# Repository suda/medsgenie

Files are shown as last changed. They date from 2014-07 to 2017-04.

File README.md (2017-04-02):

# Internet connected pill dispenser

## Revisions

### Mark I

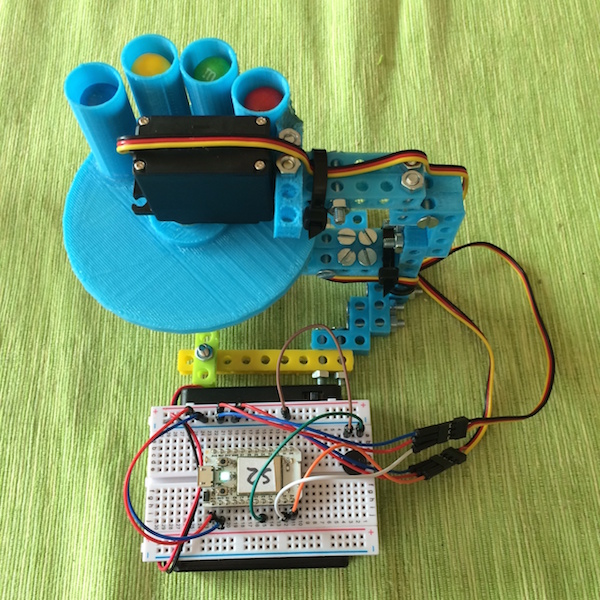
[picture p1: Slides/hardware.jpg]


Done during [BattleHack Warsaw](https://2014.battlehack.org/warsaw/) hackathon (got 2nd place).

TODO: Mention bitbeam

### Mark II

![]()

Revised version made for CNBC Cloud Challenge show. Improvements include less parts requiring glue and built in studs for servos. Device also contains a screen and a button.

### Mark III aka "Gato"

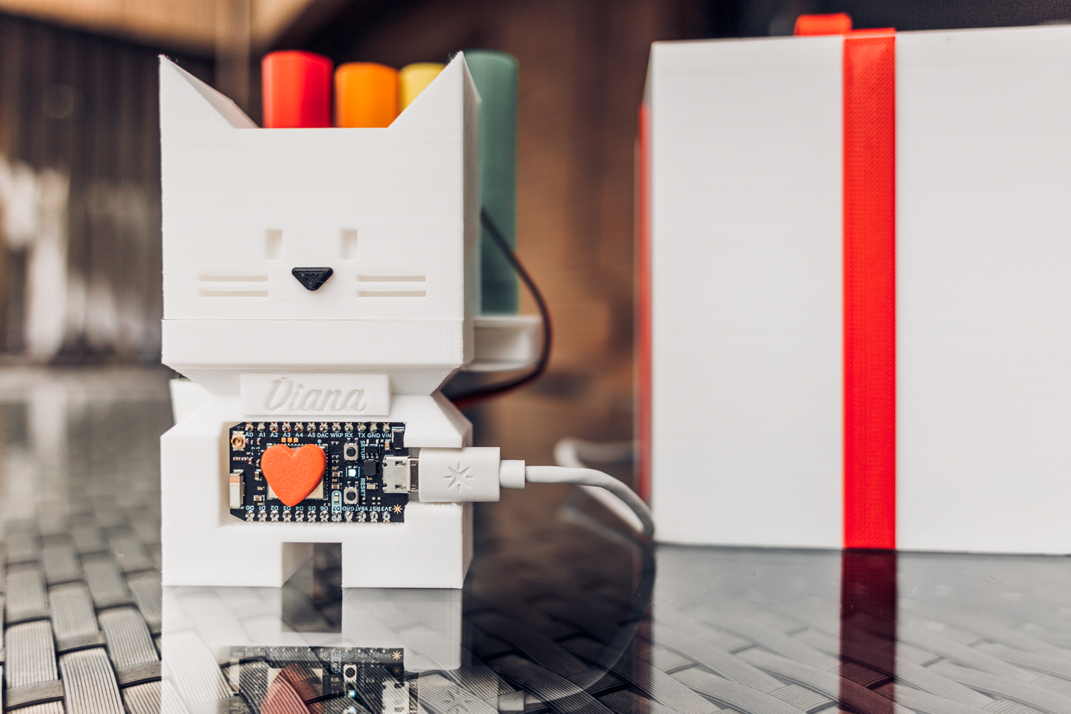
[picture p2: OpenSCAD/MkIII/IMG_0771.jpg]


Custom build as a gift. Stylized to look as a cat and comes with [it's own webapp](Gato).

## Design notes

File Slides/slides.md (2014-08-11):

# 💊 Meds Genie

---

# Grandma
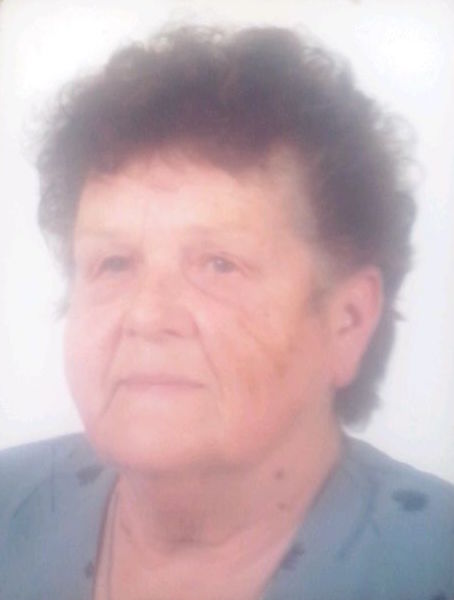
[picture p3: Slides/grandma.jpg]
Halina Szymczak


---

# Automatic Pill Dispenser
Hardware

---

# Spark Core
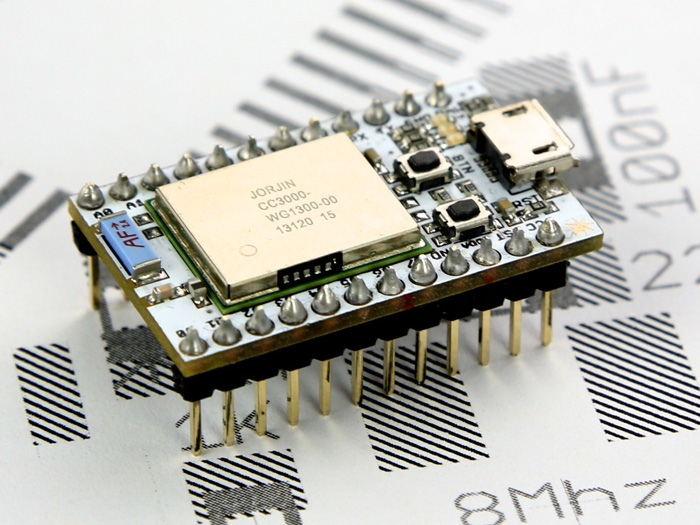
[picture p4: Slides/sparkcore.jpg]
Spark Core


---

# All 3D Printed during BattleHack
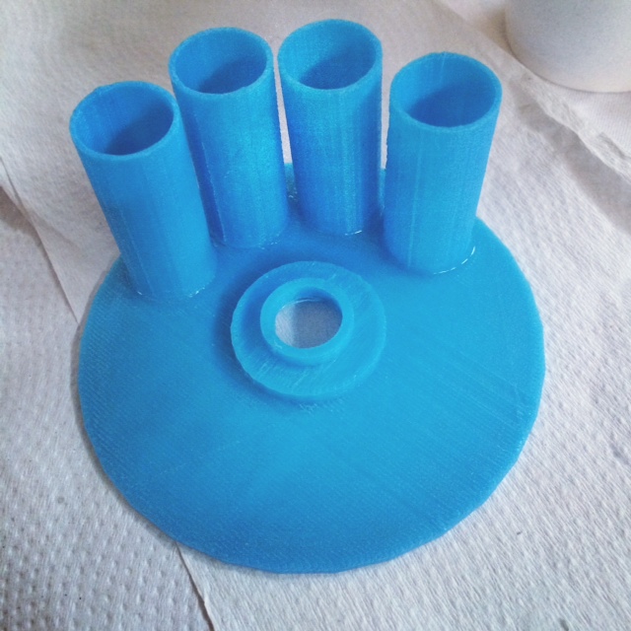
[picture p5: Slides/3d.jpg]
3D Printed Parts


---

# App for grandkids
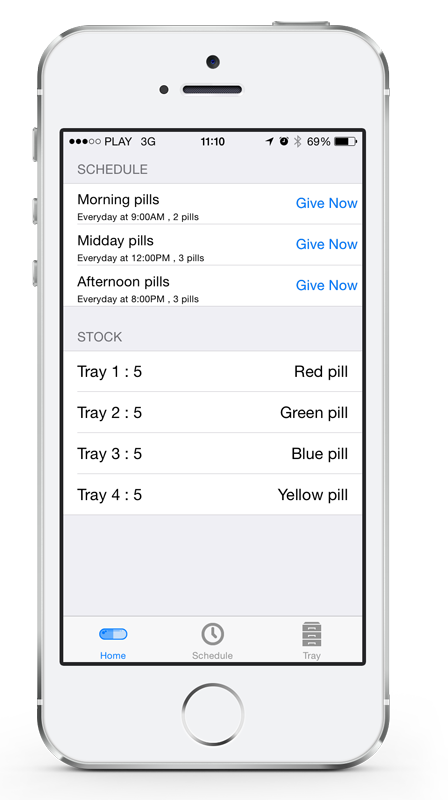
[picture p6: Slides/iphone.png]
iPhone Companion App


---

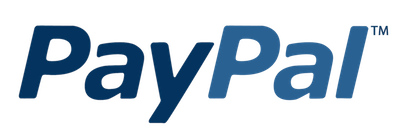
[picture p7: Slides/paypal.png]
PayPal

# Future Payments

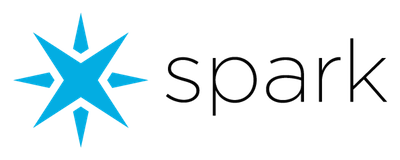
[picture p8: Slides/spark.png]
Spark Cloud

# Spark Cloud

---

# Demo Time

---

# https://github.com/suda/medsgenie

---

# Wojtek Chojnacki @chojnac
# Wojtek Siudzinski @suda

---

# 💊 Meds Genie

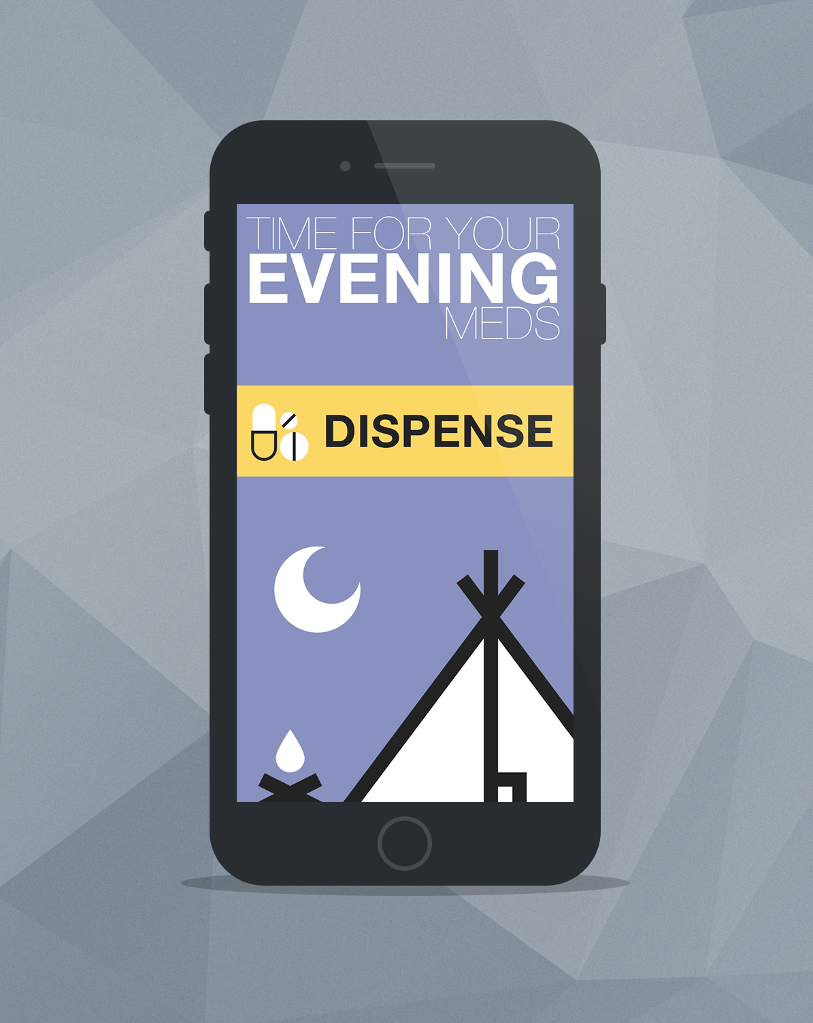
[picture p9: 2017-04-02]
mockup.png

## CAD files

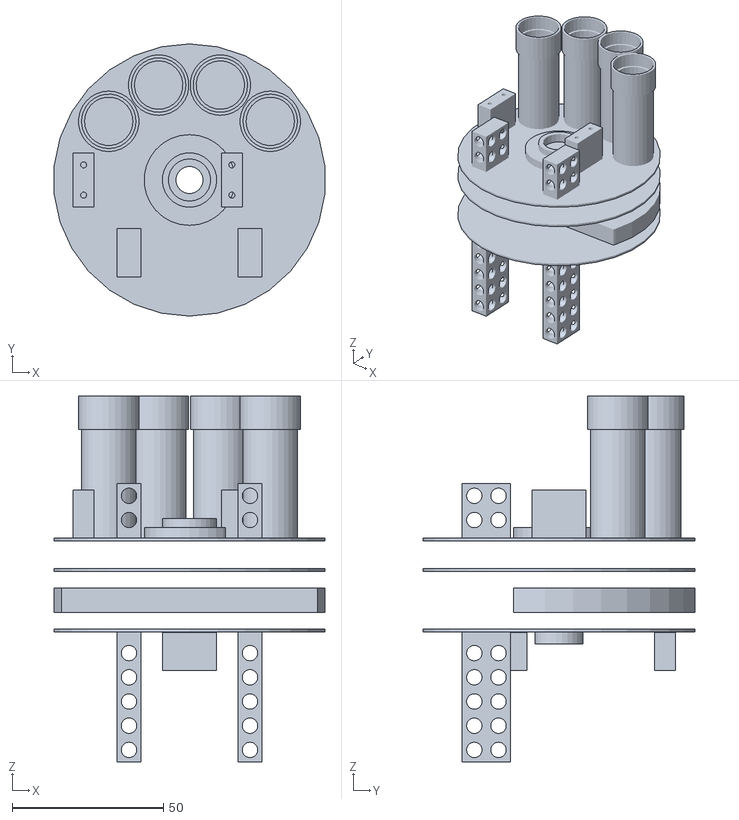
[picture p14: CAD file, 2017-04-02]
OpenSCAD/MkII/complete.stl
89.5 x 90.0 x 121.0

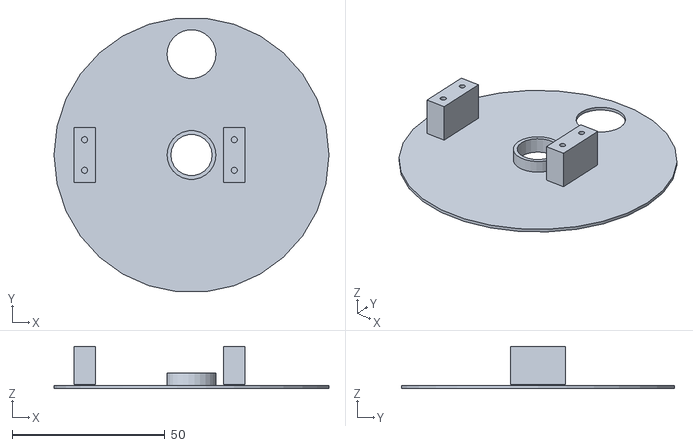
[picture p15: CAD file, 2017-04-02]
OpenSCAD/MkII/wheel4_simple.stl
90.0 x 89.5 x 13.8

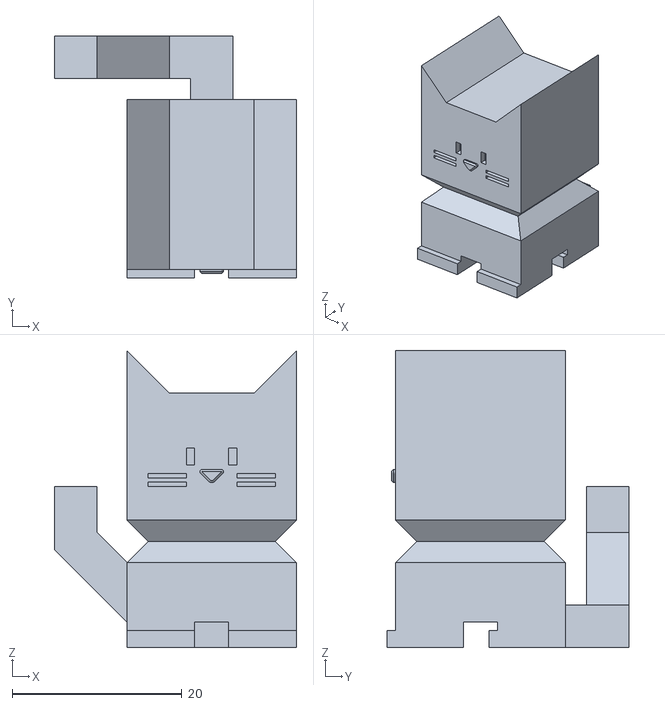
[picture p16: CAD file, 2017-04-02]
OpenSCAD/MkIII/calicat.stl
28.5 x 28.5 x 35.0

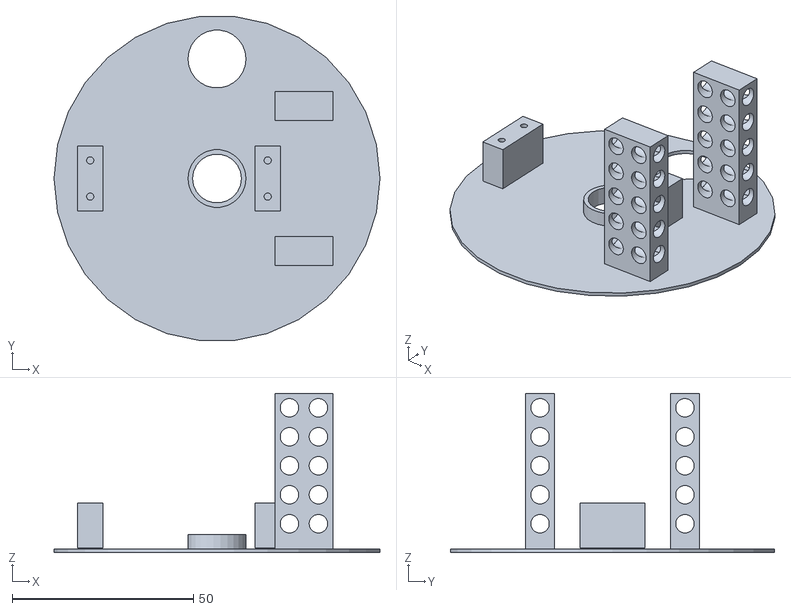
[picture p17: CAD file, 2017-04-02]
OpenSCAD/MkII/wheel4.stl
90.0 x 89.5 x 44.0

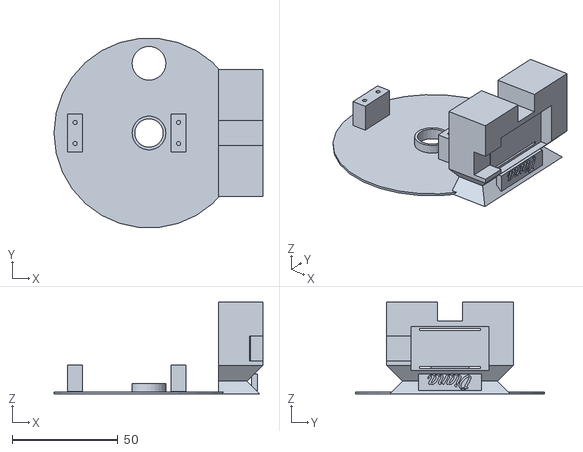
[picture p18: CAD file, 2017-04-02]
OpenSCAD/MkIII/wheel4_gato.stl
99.0 x 89.5 x 43.5

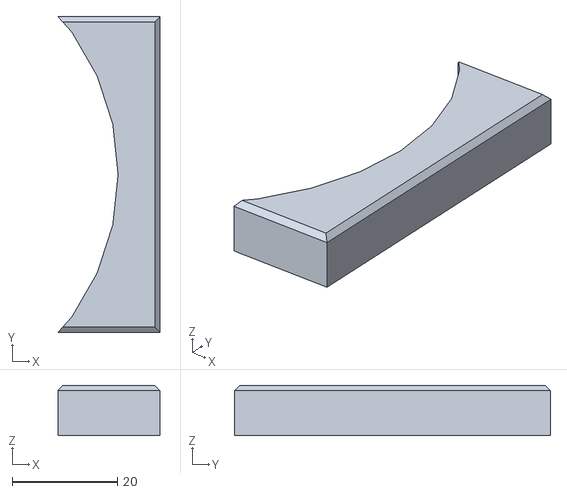
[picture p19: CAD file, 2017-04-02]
OpenSCAD/MkIII/middle_gato.stl
19.5 x 60.0 x 9.50

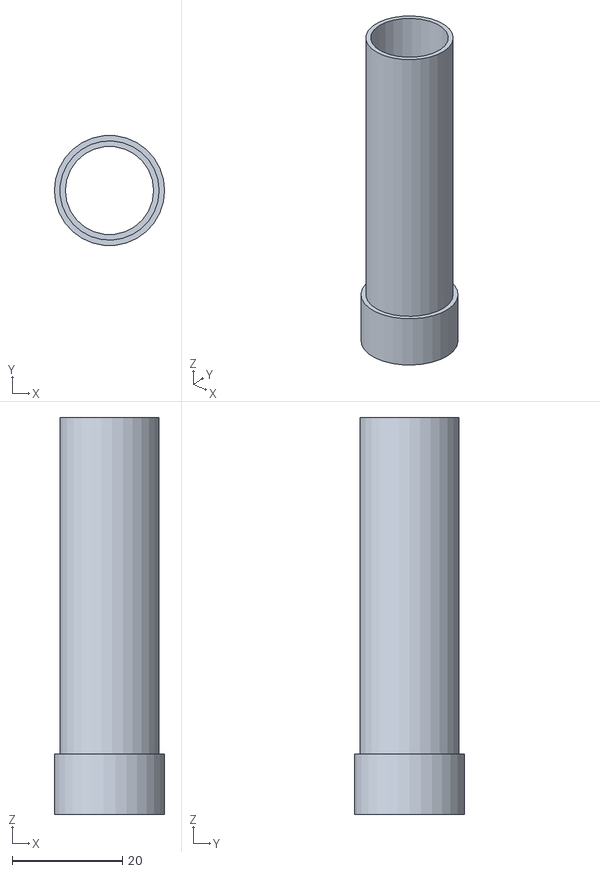
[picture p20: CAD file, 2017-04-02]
OpenSCAD/MkII/tube.stl
20.0 x 19.9 x 72.0

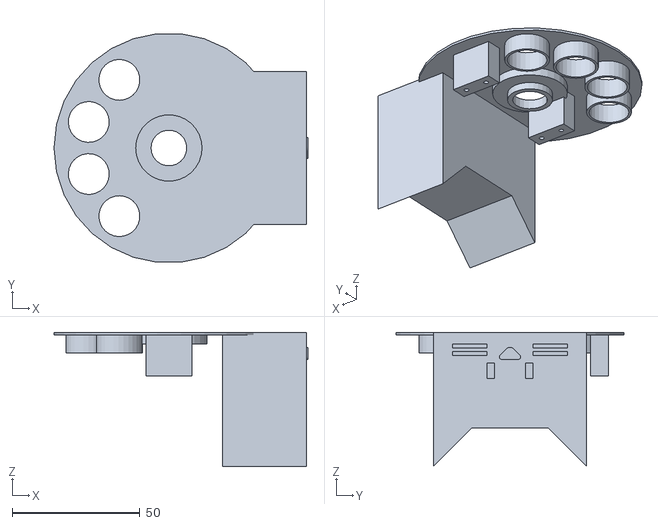
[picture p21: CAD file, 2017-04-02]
OpenSCAD/MkIII/wheel1_gato.stl
99.5 x 89.5 x 52.5

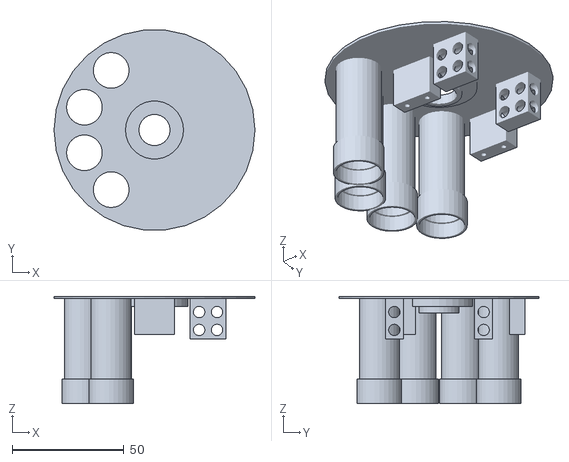
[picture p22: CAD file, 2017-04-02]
OpenSCAD/MkII/wheel1.stl
90.0 x 89.5 x 48.0

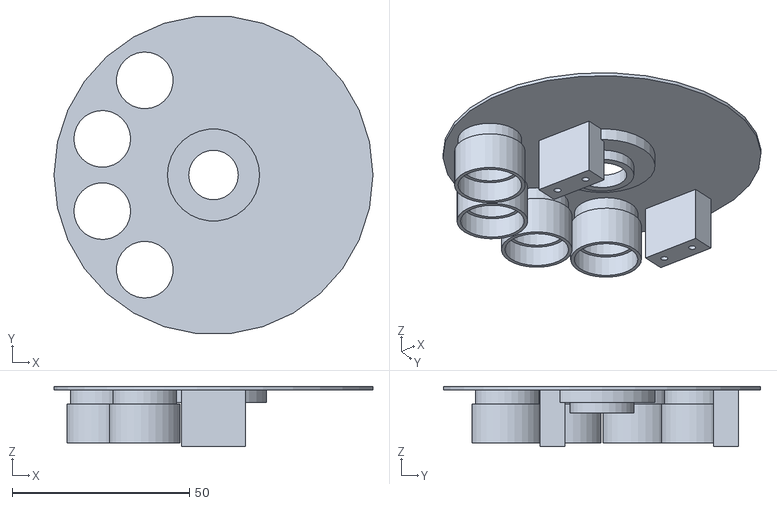
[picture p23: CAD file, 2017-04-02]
OpenSCAD/MkII/wheel1_simple.stl
90.0 x 89.5 x 17.0

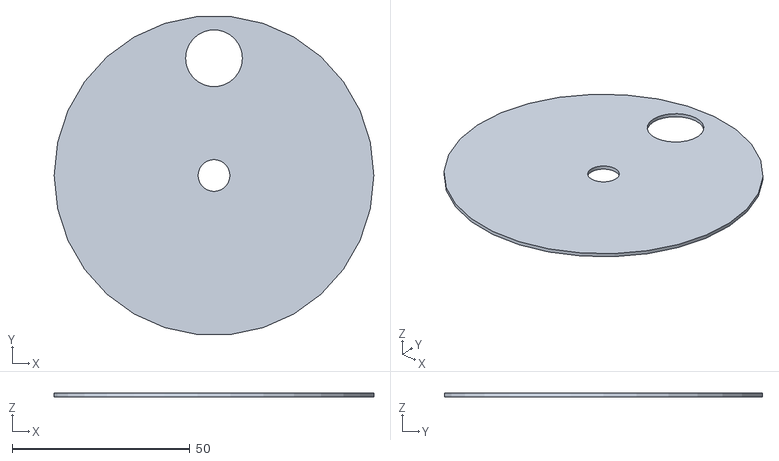
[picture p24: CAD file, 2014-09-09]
OpenSCAD/MkII/wheel2.stl
90.0 x 89.5 x 1.00

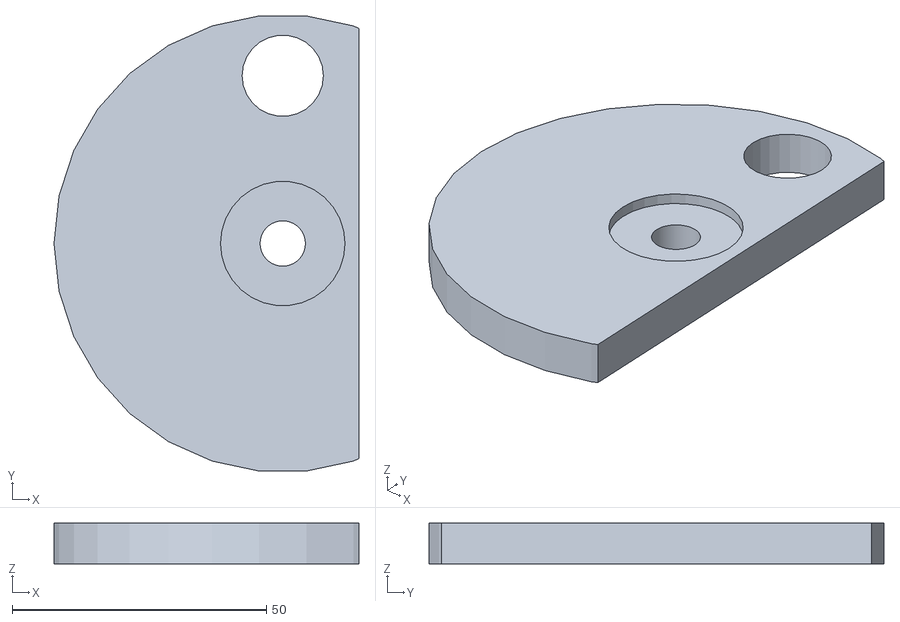
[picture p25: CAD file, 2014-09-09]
OpenSCAD/MkII/wheel3.stl
60.0 x 89.5 x 8.00

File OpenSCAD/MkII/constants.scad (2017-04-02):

//-------------------------------------------------------------
//-- Futaba Horn from Servo wheel by Juan Gonzalez (obijuan) juan@iearobotics.com
//-------------------------------------------------------------

//-- Wheel parameters
wheel_or_idiam = 50;                   //-- O-ring inner diameter
wheel_or_diam = 1;                     //-- O-ring section diameter
wheel_height = 2*wheel_or_diam+0;     //-- Wheel height: change the 0 for 
                                      //-- other value (0 equals minimun height)
//-- Parameters common to all horns
horn_drill_diam = 2;
horn_height = 8;        //-- Total height: shaft + plate
horn_plate_height = 2;  //-- plate height

//-- Futaba 3003 servo rounded horn parameters
rh_diam1 = 8.5;  //-- Rounded horn small diameter
rh_diam2 = 24; //-- Rounded horn big diameter
rounded_horn_drill_distance = 7.3;

//-- Futaba 3003 4-arm horn parameters
a4h_end_diam = 5;
a4h_center_diam = 10;
a4h_arm_length = 15;
a4h_drill_distance = 13.3;

//-- Pill parameters
pill_diam = 16;
pill_height = 8;
pill_holder = pill_diam * 1.5;

length = 70;


module motorPeg(height=12.5) {
    difference() {
        cube([7, 18, height], center=true);
        translate([0, -5, 0])
            cylinder(r=1, h=20, center=true, $fn=100);
        translate([0, 5, 0])
            cylinder(r=1, h=20, center=true, $fn=100);
    }
}

module gato() {
    scale(3)
        rotate([180, 0, -90])
            difference() {
                import("calicat.stl", convexity=3);
                translate([0, 8, 0])
                    cube([50, 50, 50]);
            }
}

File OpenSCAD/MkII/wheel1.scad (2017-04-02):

include <constants.scad>;
include <bitbeam-beam.scad>;
include <tube.scad>;

module handle() {
    union() {
        cube([2.5, 8*2, 8]);
        translate([2.5, 0, 0])
            beam(2);            
        translate([2.5, 8, 0])
            beam(2);
    }
}

module wheel1() {
	difference() {
		cylinder(r=45, h=1, center=true);
		for (i = [1 : 4]) {
			translate([0, 0, 0])
			rotate([0,0,i*36])
				translate([0, 33, -1])
					cylinder(h=3, r=(pill_diam + 1.5) / 2);
		}

		translate([0, 0, -1])
			cylinder(r=13, h=2);
	}

	difference() {
		union() {
			translate([0, 0, -4])
				cylinder(r=15, h=4);

			translate([0, 0, -7])
				cylinder(r=9, h=3);
            
            rotate([0, 0, 270])
                translate([-35, 0, -8.5])
                    motorPeg(12+4);
            
            rotate([0, 0, 270])
                translate([14, 0, -8.5])
                    motorPeg(12+4);
		}

		translate([0, 0, -3])
			cylinder(r=13.5, h=4);

		translate([0, 0, -8])
				cylinder(r=7, h=6);
	}
    
    
	pills = 1;
	for (i = [1 : 4]) {
		translate([0, 0, -(pill_height * pills) + 1.5])
			rotate([0,0,i*36])
				translate([0, 33, -1])
					tube(pills);
	}
    
//    translate([8*2, -8*2, 0])
//        rotate([90, 90, 0])
//            handle();
//    
//    translate([8*2, 8*3, 0])
//        rotate([90, 90, 0])
//            handle();
}

//wheel1();

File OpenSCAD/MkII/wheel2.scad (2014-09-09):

include <constants.scad>;

module wheel2() {
	difference() {
		cylinder(r=45, h=1, center=true);
		for (i = [0 : 0]) {
			translate([0, 0, 0])
			rotate([0,0,i*36])
				translate([0, 33, -1])
					cylinder(h=3, r=pill_diam / 2);
		}

		//-- Inner drill
		translate([0, 0, -pill_height / 2])
			cylinder(h=pill_height, r=rh_diam1/2+0.2,$fn=100);

		//-- Carved circle for the Futaba rounded horn
		translate([0, 0, pill_height / 2 - 2])
			cylinder(r=rh_diam2/2+0.25, h=2.1, $fn=30);
	}
}

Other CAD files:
OpenSCAD/MkII/bitbeam-beam.scad
OpenSCAD/MkII/complete.scad
OpenSCAD/MkII/tube.scad
OpenSCAD/MkII/wheel3.scad
OpenSCAD/MkII/wheel4.scad
OpenSCAD/MkIII/complete_gato.scad
OpenSCAD/MkIII/middle_gato.scad
OpenSCAD/MkIII/tube.scad
OpenSCAD/MkIII/wheel1_gato.scad
OpenSCAD/MkIII/wheel3.scad
OpenSCAD/MkIII/wheel4_gato.scad

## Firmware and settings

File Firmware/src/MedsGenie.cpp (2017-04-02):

#include <Arduino.h>
#include <Debounce.h>
#include <U8x8lib.h>
#include "application.h"

#ifdef U8X8_HAVE_HW_SPI
#include <SPI.h>
#endif
#ifdef U8X8_HAVE_HW_I2C
#include <Wire.h>
#endif

SYSTEM_THREAD(ENABLED);

#include "pitches.h"
#include "types.h"

// Pins
int lockServoPin = A4;
int transportServoPin = D0;
int buzzerPin = RX;
int CLKPin = A3;
int MOSIPin = A5;
int RESPin = A0;
int DCPin = A1;
int CSPin = A2;
int btnPin = D1;

int numberOfTrays = 4;
int servoDelay = 200;
int lastLockPosition = 0;
int lastTransportPosition = 0;
int lockAngles[] = {170, 140, 98, 56, 17};
int transportAngles[] = {16, 45, 86, 128, 168};
/*int lockAngles[] = {180, 140, 100, 63, 22};
int transportAngles[] = {11, 45, 86, 128, 168};*/
bool isSignaling;
bool switchState;
unsigned long bootTime;
bool alreadyEnteredListenMode;

int melody[] = {
  NOTE_C4, NOTE_G3,NOTE_G3, NOTE_A3, NOTE_G3, 0, NOTE_B3, NOTE_C4};
int noteDurations[] = { 4, 8, 8, 4, 4, 4, 4, 4 };
state_type state = READY;

//#define USE_SCREEN

// LED status for the test signal that can be triggered from the cloud
class LEDCloudSignalStatus: public LEDStatus {
public:
  explicit LEDCloudSignalStatus(LEDPriority priority) :
        LEDStatus(LED_PATTERN_CUSTOM, priority),
        ticks_(0),
        index_(0) {
    updateColor();
  }

protected:
  virtual void update(system_tick_t t) override {
    if (t >= ticks_) {
      // Change LED color
      if (++index_ == COLOR_COUNT) {
        index_ = 0;
      }
      updateColor();
    } else {
      ticks_ -= t; // Update timing
    }
  }

private:
  uint16_t ticks_;
  uint8_t index_;

  void updateColor() {
    setColor(COLORS[index_]);
    ticks_ = 100;
  }

  static const uint32_t COLORS[];
  static const size_t COLOR_COUNT;
};
const uint32_t LEDCloudSignalStatus::COLORS[] = { 0xEE82EE, 0x4B0082, 0x0000FF, 0x00FF00, 0xFFFF00, 0xFFA500, 0xFF0000 }; // VIBGYOR
const size_t LEDCloudSignalStatus::COLOR_COUNT = sizeof(LEDCloudSignalStatus::COLORS) / sizeof(LEDCloudSignalStatus::COLORS[0]);

U8X8_SH1106_128X64_NONAME_4W_HW_SPI u8x8(CSPin, DCPin, RESPin);
Debounce button = Debounce();
Servo lockServo;
Servo transportServo;
LEDCloudSignalStatus rainbowSignal(LED_PRIORITY_IMPORTANT);

/**
 * Private functions
 */
#pragma mark Private functions

void _attachServos() {
  SPI.end();
  lockServo.attach(lockServoPin);
  transportServo.attach(transportServoPin);
}

void _updateScreen() {
  u8x8.clear();

  switch(state) {
    case READY:
      u8x8.draw2x2String(0, 1, "PRESS TO");
      u8x8.draw2x2String(0, 5, "DISPENCE");
      break;
    case WORKING:
      u8x8.draw2x2String(1, 2, "WORKING");
      u8x8.draw2x2String(1, 4, "  ...");
      break;
    case CONFIRM:
      u8x8.draw2x2String(1, 1, "CONFIRM");
      u8x8.draw2x2String(1, 5, "   ?");
      break;
  }

  u8x8.refreshDisplay();
}

void _setNewState(state_type newState) {
  state = newState;
#ifdef USE_SCREEN
  _updateScreen();
#endif
}

void _lockTo(int pos, bool skipDelay=false) {
  _attachServos();
  lockServo.write(lockAngles[pos]);
  if (!skipDelay) delay(servoDelay * abs(lastLockPosition - pos));
  lastLockPosition = pos;
}

void _transportTo(int pos, bool skipDelay=false) {
  _attachServos();
  transportServo.write(transportAngles[pos]);
  if (!skipDelay) delay(servoDelay * abs(lastTransportPosition - pos));
  lastTransportPosition = pos;
}

int _servePill(int pos) {
  // Test for oob position
  if ((pos < 0) || (pos > numberOfTrays - 1)) return 404;

  // 0 tray is drop zone. Increase position
  pos++;

  // Lock
  _lockTo(numberOfTrays);

  // Move transport under tray
  _transportTo(pos);

  // Unlock...
  _lockTo(pos, pos == numberOfTrays);

  // Let it drop
  delay(200);

  // Lock again
  _lockTo(4, pos == numberOfTrays);

  // Move transport to drop zone
  _transportTo(0);

  return 200;
}

/**
 * Particle functions
 */
#pragma mark Particle functions

int beepCommand(String command="") {
  for (int i=0; i<8; i++) {
    int noteDuration = 500/noteDurations[i];

    if (melody[i] == 0) {
      noTone(buzzerPin);
    } else {
      tone(buzzerPin, melody[i]);
    }

    delay(noteDuration);

    noTone(buzzerPin);
    int pauseBetweenNotes = noteDuration * 1.30;
    delay(pauseBetweenNotes);
  }

  return 200;
}

int servePillCommand(String command) {
  int returnCode;

  _setNewState(WORKING);
  SPI.end();
  lockServo.attach(lockServoPin);
  transportServo.attach(transportServoPin);
  rainbowSignal.setActive(true);

  String currentCommand = command;
  while (currentCommand.indexOf(",") > -1) {
      int pos = currentCommand.substring(0, currentCommand.indexOf(",")).toInt();
      String newCommand = currentCommand.substring(currentCommand.indexOf(",") + 1);
      currentCommand = newCommand;
      Serial.println(currentCommand);
      returnCode = _servePill(pos);
  }

  int pos = currentCommand.toInt();
  returnCode = _servePill(pos);


  rainbowSignal.setActive(false);
  u8x8.begin();
  _setNewState(CONFIRM);

  return returnCode;
}

int goToCommand(String command) {
  int pos = command.toInt();
  _lockTo(pos);
  _transportTo(pos);
  return 200;
}

int setTransCommand(String command) {
  transportServo.write(command.toInt());
  return 200;
}

int setLockCommand(String command) {
  lockServo.write(command.toInt());
  return 200;
}

int setStateCommand(String command) {
  _setNewState((state_type)command.toInt());
  return 200;
}

int notifyCommand(String command) {
  Particle.publish("pills-taken");
  return 200;
}

/**
 * Main functions
 */
#pragma mark Main functions

void setup() {
  bootTime = millis();

  lockServo.attach(lockServoPin);
  transportServo.attach(transportServoPin);

  _lockTo(0);
  _transportTo(0);

  button.attach(btnPin, INPUT_PULLUP);
  button.interval(20);

  Particle.function("serve", servePillCommand);
  Particle.function("goto", goToCommand);
  Particle.function("beep", beepCommand);

  Particle.function("trans", setTransCommand);
  Particle.function("lock", setLockCommand);
  Particle.function("state", setStateCommand);
  Particle.function("notify", notifyCommand);

  Serial.begin(9600);

#ifdef USE_SCREEN
  u8x8.begin();
  u8x8.setFont(u8x8_font_amstrad_cpc_extended_u);
#endif
  _setNewState(READY);

  System.set(SYSTEM_CONFIG_SOFTAP_PREFIX, "diana");
  System.set(SYSTEM_CONFIG_SOFTAP_SUFFIX, "hi:)");
}

void loop() {
  if (WiFi.connecting() && (millis() - bootTime > 20000) && !alreadyEnteredListenMode) {
    alreadyEnteredListenMode = true;
    WiFi.listen();
  }

  if (button.update() && (button.read() == LOW)) {
    switch(state) {
      case READY:
        servePillCommand("1,2");
        break;
      case CONFIRM:
        notifyCommand("");
        _setNewState(READY);
        break;
    }
  }
}

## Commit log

2014-07-12 Removed old code
    [Untitled.stl, guide.scad, tapped.scad]
2014-07-13 Added picture of grandma ❤ :)
2014-07-14 Current slides
2014-09-09 Cleaned up scad files
    [complete.scad, complete.stl, tube.scad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]
2014-09-09 Rotated whole model
    [complete.scad, complete.stl]
2017-04-02 Update with Mk II and Mk III
    [bitbeam-beam.scad, calicat.stl, complete.scad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]
